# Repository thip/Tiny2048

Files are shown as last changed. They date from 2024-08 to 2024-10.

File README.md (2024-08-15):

# Tiny2048

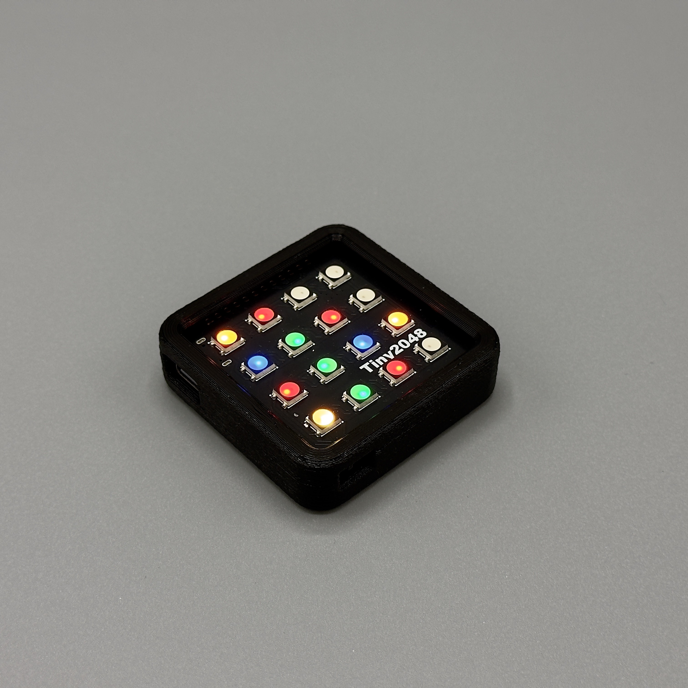
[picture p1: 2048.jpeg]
Photograph of the game running on the assembled hardware


A custom ESP32 dev board with a built in 4x4 RGB LED Matrix and accelerometer.

Built to run an RGB version of 2048 - a simple but addictive game where you try to add up to 2048 by combining matching numbers on sliding tiles. 

Read more about the project at [https://hackaday.io/project/197115-tiny2048](https://hackaday.io/project/197115-tiny2048)

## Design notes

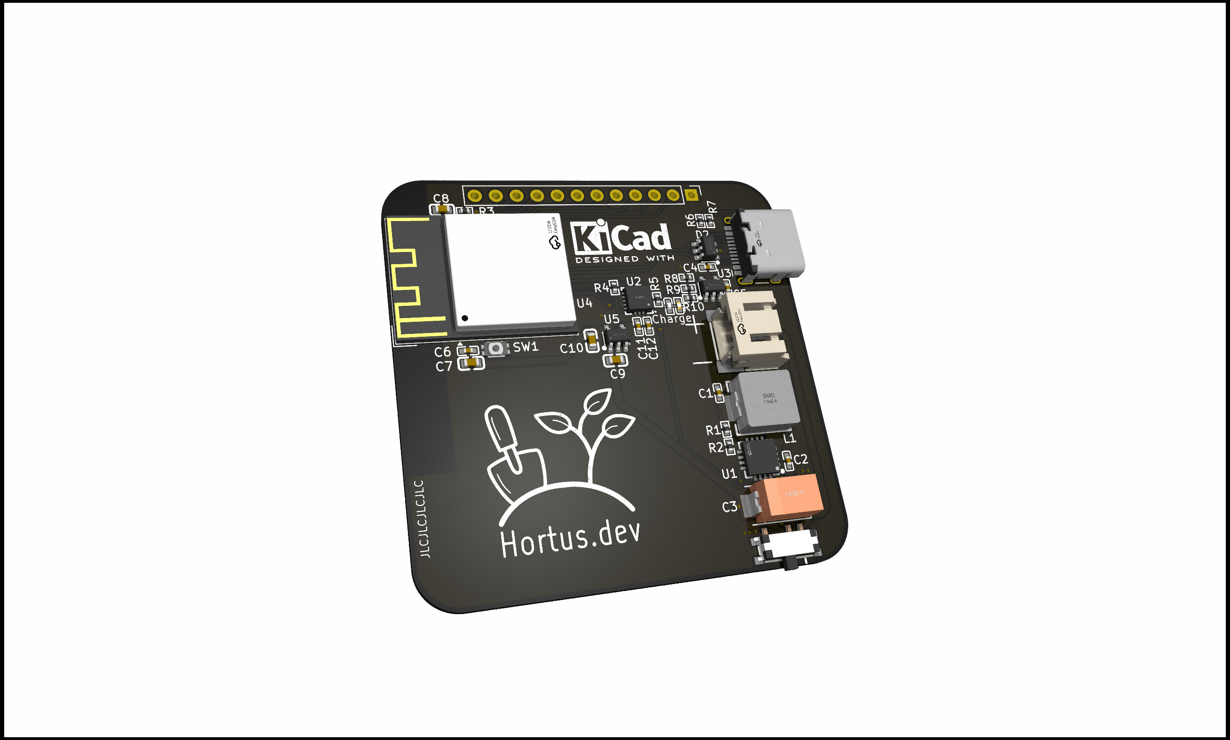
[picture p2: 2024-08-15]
hardware/tiny2048.png

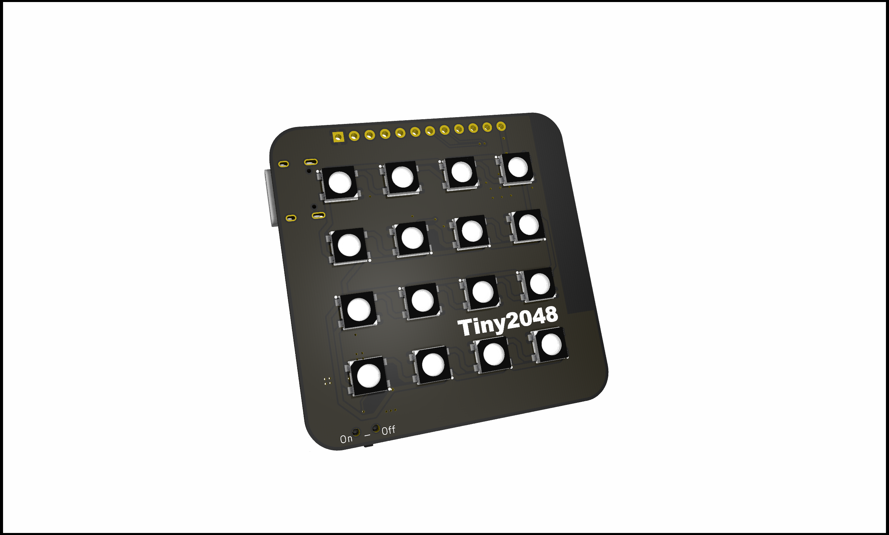
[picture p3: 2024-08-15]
hardware/tiny2048_f.png

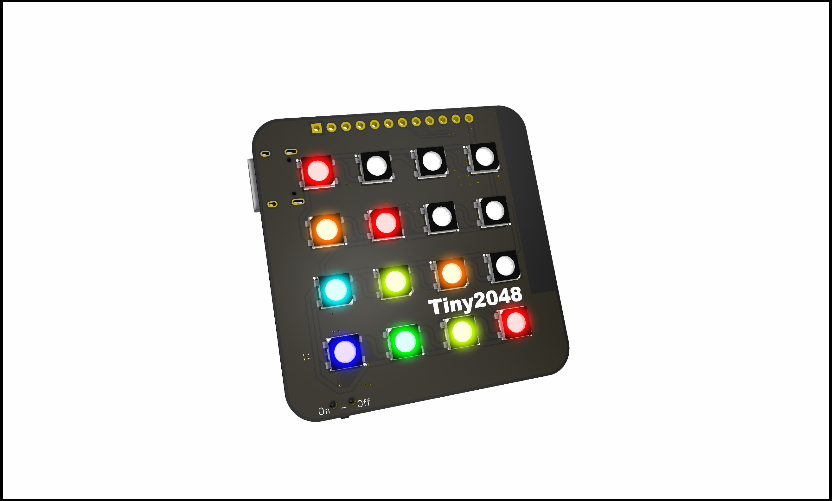
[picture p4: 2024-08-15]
hardware/tiny2048_f_lit.png

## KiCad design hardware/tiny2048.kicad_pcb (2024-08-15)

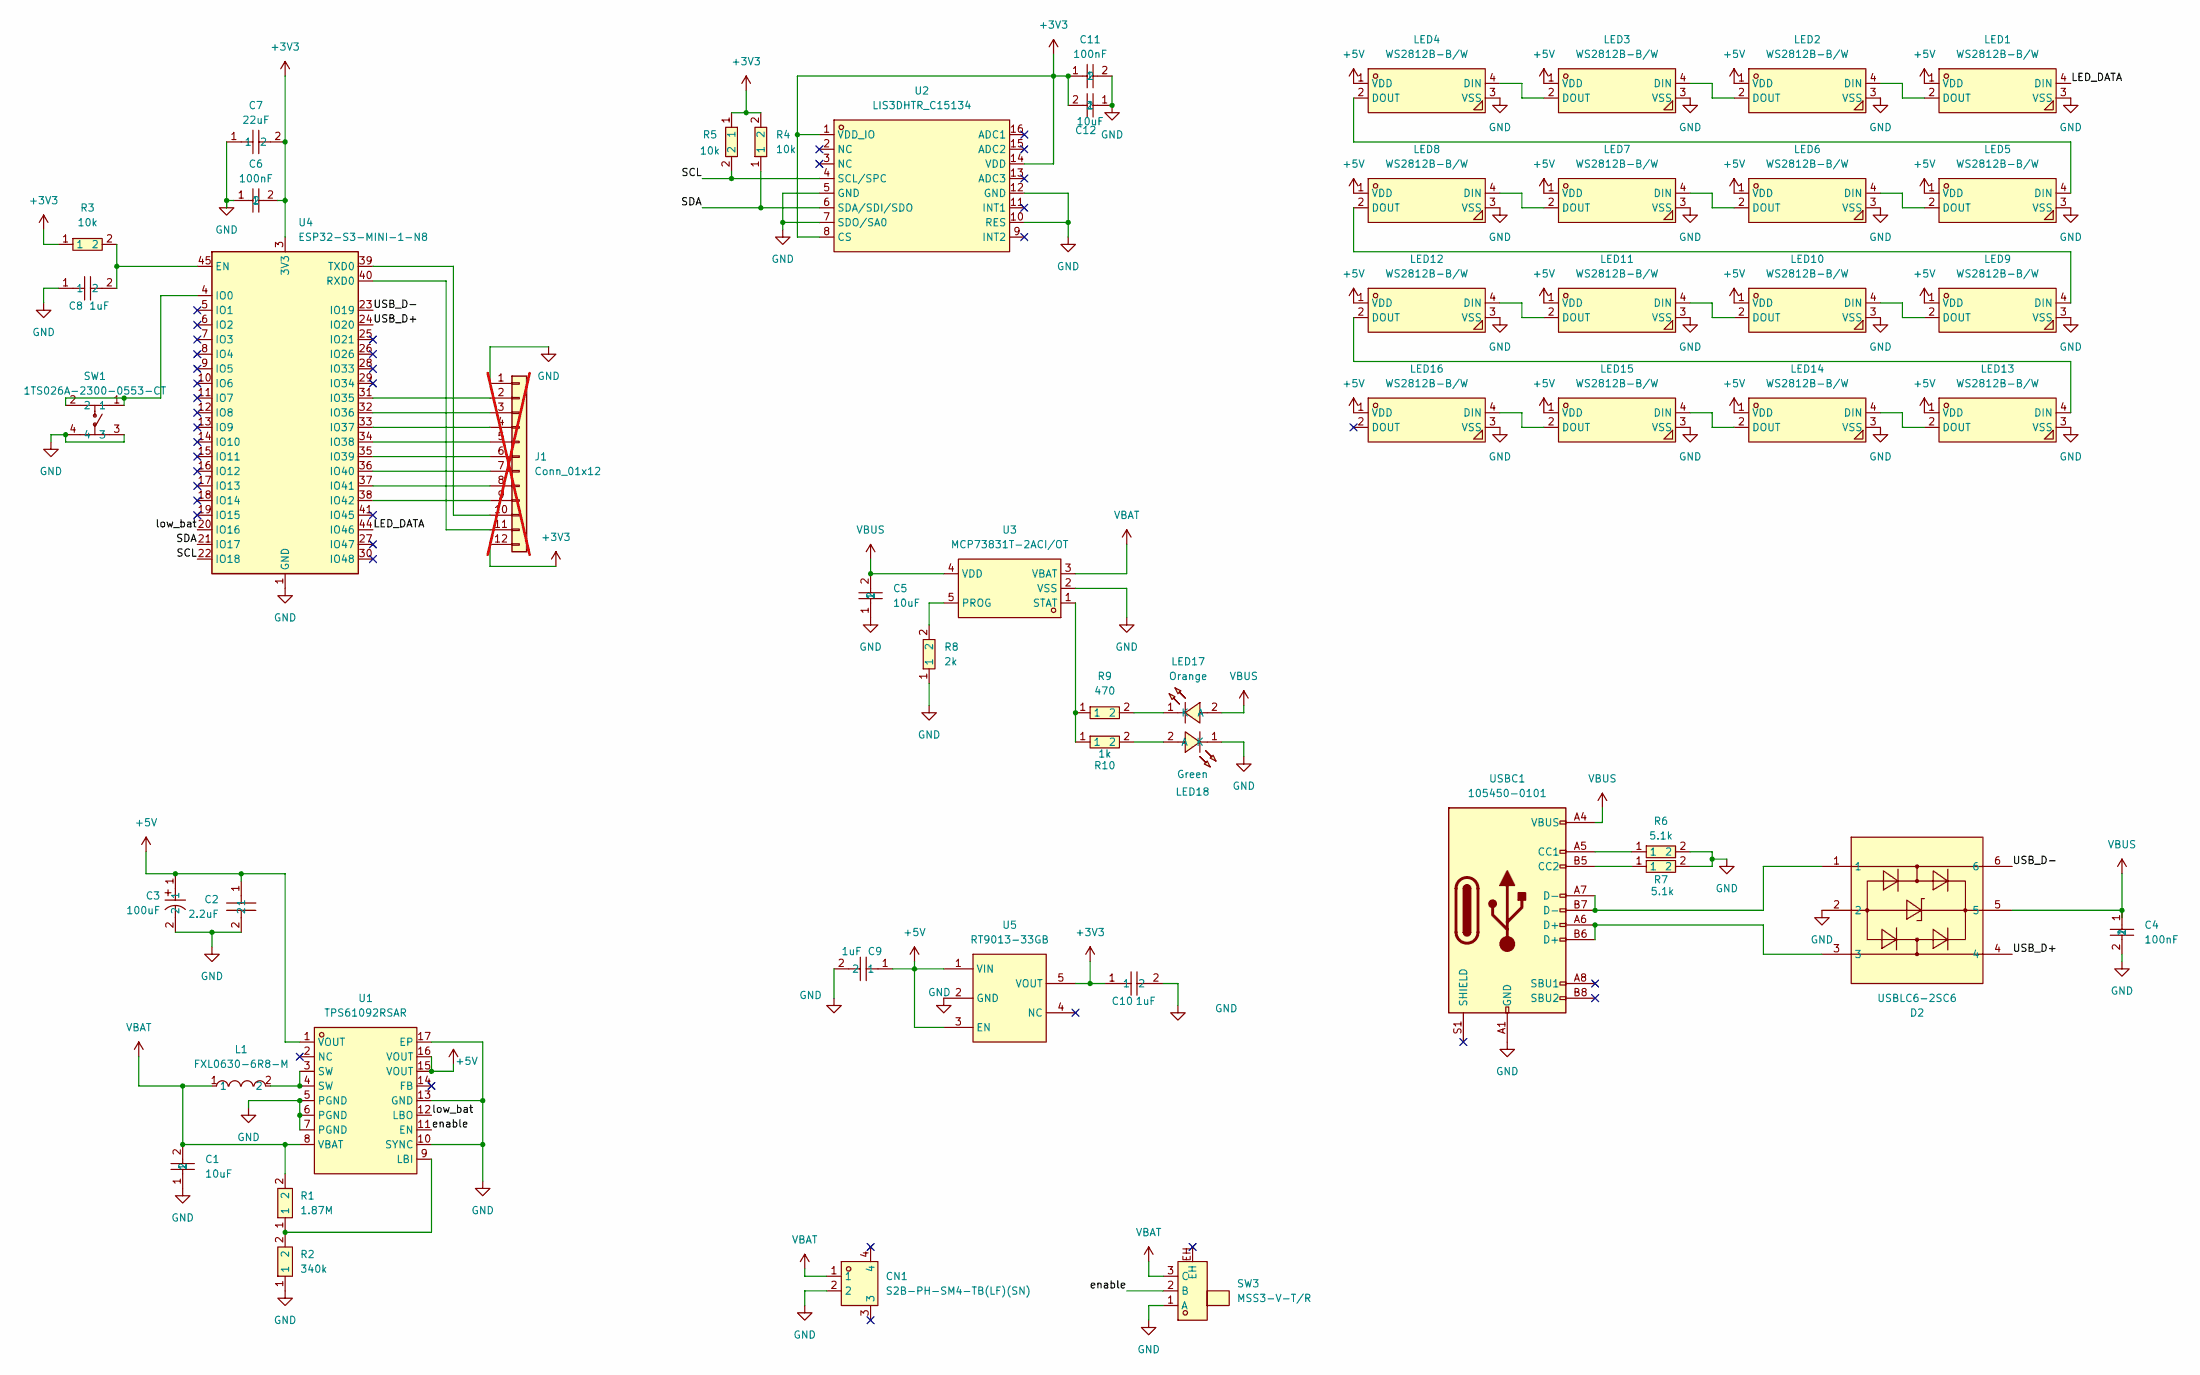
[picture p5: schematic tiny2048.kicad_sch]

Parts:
C1, C5, C12: 10uF; C0402; LCSC Part C15525
C2: 2.2uF; C0402; LCSC Part C12530
C3: 100uF; CAP-SMD_L7.3-W4.3-FD; LCSC Part C215892
C4, C6, C11: 100nF; C0402; LCSC Part C1525
C7: 22uF; C0603; LCSC Part C59461
C8, C9, C10: 1uF; C0603; LCSC Part C15849
CN1: S2B-PH-SM4-TB(LF)(SN); CONN-SMD_P2.00_S2B-PH-SM4-TB-LF-SN; LCSC Part C295747
D2: USBLC6-2SC6; SOT-23-6_L2.9-W1.6-P0.95-LS2.8-BL; LCSC Part C7519
J1: Conn_01x12; PinHeader_1x12_P2.54mm_Vertical; not fitted
L1: FXL0630-6R8-M; IND-SMD_L7.0-W6.6; LCSC Part C167221
LED1, LED2, LED3, LED4, LED5, LED6, LED7, LED8, LED9, LED10, LED11, LED12, LED13, LED14, LED15, LED16: WS2812B-B/W; LED-SMD_4P-L5.0-W5.0-TL_WS2812B-B; LCSC Part C2761795
LED17: Orange; LED0402-RD_ORANGE; LCSC Part C965791
LED18: Green; LED0402-RD_BLUE; LCSC Part C965797
R1: 1.87M; R0402; LCSC Part C368349
R2: 340k; R0402; LCSC Part C409910
R3, R4, R5: 10k; R0402; LCSC Part C25744
R6, R7: 5.1k; R0402; LCSC Part C25905
R8: 2k; R0402; LCSC Part C4109
R9: 470; R0402; LCSC Part C25117
R10: 1k; R0402; LCSC Part C11702
SW1: 1TS026A-2300-0553-CT; SW-SMD_4P-L2.6-W1.6-P0.75-LS3.0; LCSC Part C913791
SW3: MSS3-V-T/R; SW-SMD_MSS3-V-T-R; LCSC Part C495932
U1: TPS61092RSAR; QFN-16_L4.0-W4.0-P0.65-BL-EP2.7-1; LCSC Part C2878944
U2: LIS3DHTR_C15134; LGA-16_L3.0-W3.0-P0.50-TL; LCSC Part C15134
U3: MCP73831T-2ACI/OT; SOT-23-5_L3.0-W1.7-P0.95-LS2.8-BL; LCSC Part C424093
U4: ESP32-S3-MINI-1-N8; ESP32-S2-MINI-1; LCSC Part C2913206
U5: RT9013-33GB; SOT-23-5_L3.0-W1.7-P0.95-LS2.8-BL; LCSC Part C47773
USBC1: 105450-0101; USB_C_Receptacle_HCTL_HC-TYPE-C-16P-01A; LCSC Part C2894897

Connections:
+3V3: C6.2, C7.2, C10.1, C11.1, C12.2, J1.12, R3.1, R4.2, R5.1, U2.1 (VDD_IO), U2.8 (CS), U2.14 (VDD), U4.3 (3V3), U5.5 (VOUT)
+5V: C2.1, C3.1, C9.1, LED1.1 (VDD), LED2.1 (VDD), LED3.1 (VDD), LED4.1 (VDD), LED5.1 (VDD), LED6.1 (VDD), LED7.1 (VDD), LED8.1 (VDD), LED9.1 (VDD), LED10.1 (VDD), LED11.1 (VDD), LED12.1 (VDD), LED13.1 (VDD), LED14.1 (VDD), LED15.1 (VDD), LED16.1 (VDD), U1.1 (VOUT), U1.15 (VOUT), U1.16 (VOUT), U5.1 (VIN), U5.3 (EN)
/LED_DATA: LED1.4 (DIN), U4.44 (IO46)
/SCL: R5.2, U2.4 (SCL/SPC), U4.22 (IO18)
/SDA: R4.1, U2.6 (SDA/SDI/SDO), U4.21 (IO17)
/USB_D+: D2.4, U4.24 (IO20)
/USB_D-: D2.6, U4.23 (IO19)
/enable: SW3.2 (B), U1.11 (EN)
/low_bat: U1.12 (LBO), U4.20 (IO16)
GND: C1.1, C2.2, C3.2, C4.2, C5.1, C6.1, C7.1, C8.1, C9.2, C10.2, C11.2, C12.1, CN1.2, D2.2, J1.1, LED1.3 (VSS), LED2.3 (VSS), LED3.3 (VSS), LED4.3 (VSS), LED5.3 (VSS), LED6.3 (VSS), LED7.3 (VSS), LED8.3 (VSS), LED9.3 (VSS), LED10.3 (VSS), LED11.3 (VSS), LED12.3 (VSS), LED13.3 (VSS), LED14.3 (VSS), LED15.3 (VSS), LED16.3 (VSS), LED18.1 (K), R2.1, R6.2, R7.2, R8.1, SW1.3, SW1.4, SW3.1 (A), U1.5 (PGND), U1.6 (PGND), U1.7 (PGND), U1.10 (SYNC), U1.13 (GND), U1.17 (EP), U2.5 (GND), U2.7 (SDO/SA0), U2.10 (RES), U2.12 (GND), U3.2 (VSS), U4.1 (GND), U4.2 (GND), U4.42 (GND), U4.43 (GND), U4.46 (GND), U4.47 (GND), U4.48 (GND), U4.49 (GND), U4.50 (GND), U4.51 (GND), U4.52 (GND), U4.53 (GND), U4.54 (GND), U4.55 (GND), U4.56 (GND), U4.57 (GND), U4.58 (GND), U4.59 (GND), U4.60 (GND), U4.61 (GND), U4.62 (GND), U4.63 (GND), U4.64 (GND), U4.65 (GND), U5.2 (GND), USBC1.A1 (GND), USBC1.A12 (GND), USBC1.B1 (GND), USBC1.B12 (GND)
unnamed: D2.1, USBC1.A7 (D-), USBC1.B7 (D-)
unnamed: D2.3, USBC1.A6 (D+), USBC1.B6 (D+)
unnamed: J1.2, U4.31 (IO35)
unnamed: J1.3, U4.32 (IO36)
unnamed: J1.4, U4.33 (IO37)
unnamed: J1.5, U4.34 (IO38)
unnamed: J1.6, U4.35 (IO39)
unnamed: J1.7, U4.36 (IO40)
unnamed: J1.8, U4.37 (IO41)
unnamed: J1.9, U4.38 (IO42)
unnamed: J1.10, U4.39 (TXD0)
unnamed: J1.11, U4.40 (RXD0)
unnamed: L1.2, U1.3 (SW), U1.4 (SW)
unnamed: LED1.2 (DOUT), LED2.4 (DIN)
unnamed: LED2.2 (DOUT), LED3.4 (DIN)
unnamed: LED3.2 (DOUT), LED4.4 (DIN)
unnamed: LED4.2 (DOUT), LED5.4 (DIN)
unnamed: LED5.2 (DOUT), LED6.4 (DIN)
unnamed: LED6.2 (DOUT), LED7.4 (DIN)
unnamed: LED7.2 (DOUT), LED8.4 (DIN)
unnamed: LED8.2 (DOUT), LED9.4 (DIN)
unnamed: LED9.2 (DOUT), LED10.4 (DIN)
unnamed: LED10.2 (DOUT), LED11.4 (DIN)
unnamed: LED11.2 (DOUT), LED12.4 (DIN)
unnamed: LED12.2 (DOUT), LED13.4 (DIN)
unnamed: LED13.2 (DOUT), LED14.4 (DIN)
unnamed: LED14.2 (DOUT), LED15.4 (DIN)
unnamed: LED15.2 (DOUT), LED16.4 (DIN)
unnamed: LED17.1 (K), R9.2
unnamed: LED18.2 (A), R10.2
unnamed: R1.1, R2.2, U1.9 (LBI)
unnamed: R8.2, U3.5 (PROG)
unnamed: R9.1, R10.1, U3.1 (STAT)
unnamed: C8.2, R3.2, U4.45 (EN)
unnamed: SW1.1, SW1.2, U4.4 (IO0)
unnamed: R6.1, USBC1.A5 (CC1)
unnamed: R7.1, USBC1.B5 (CC2)
VBAT: C1.2, CN1.1, L1.1, R1.2, SW3.3 (C), U1.8 (VBAT), U3.3 (VBAT)
VBUS: C4.1, C5.2, D2.5, LED17.2 (A), U3.4 (VDD), USBC1.A4 (VBUS), USBC1.A9 (VBUS), USBC1.B4 (VBUS), USBC1.B9 (VBUS)

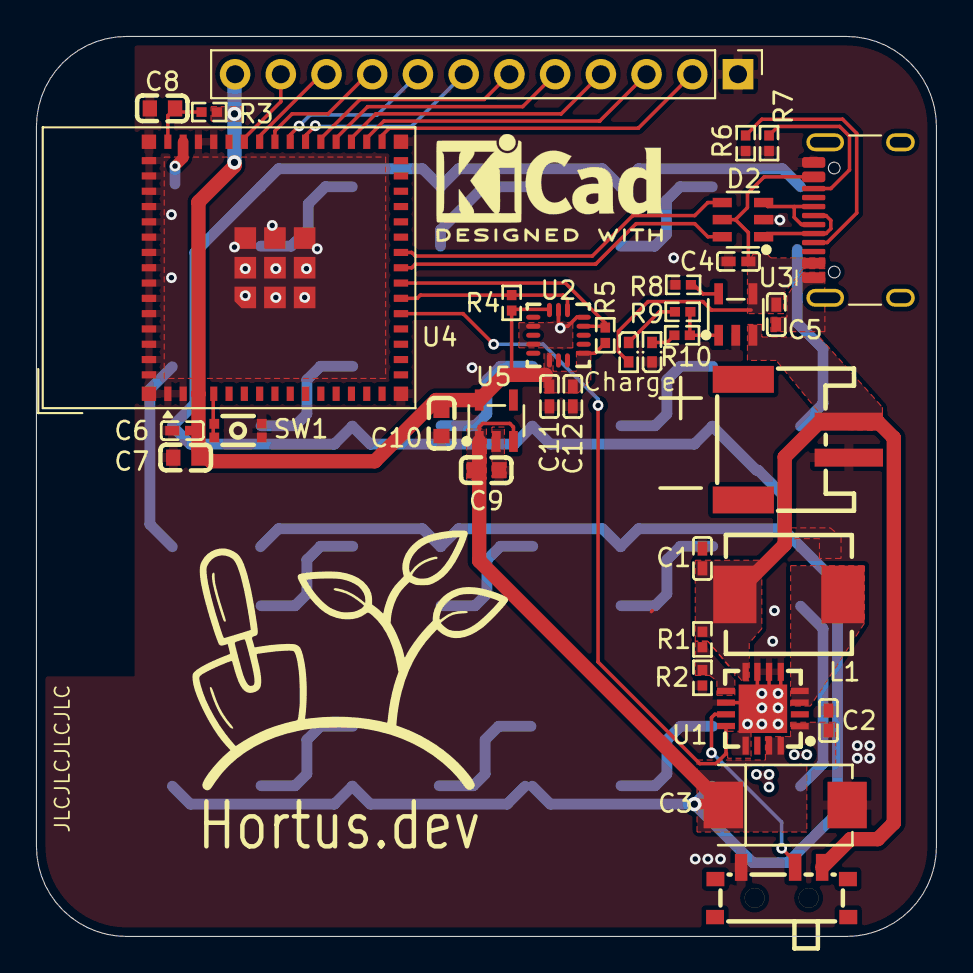
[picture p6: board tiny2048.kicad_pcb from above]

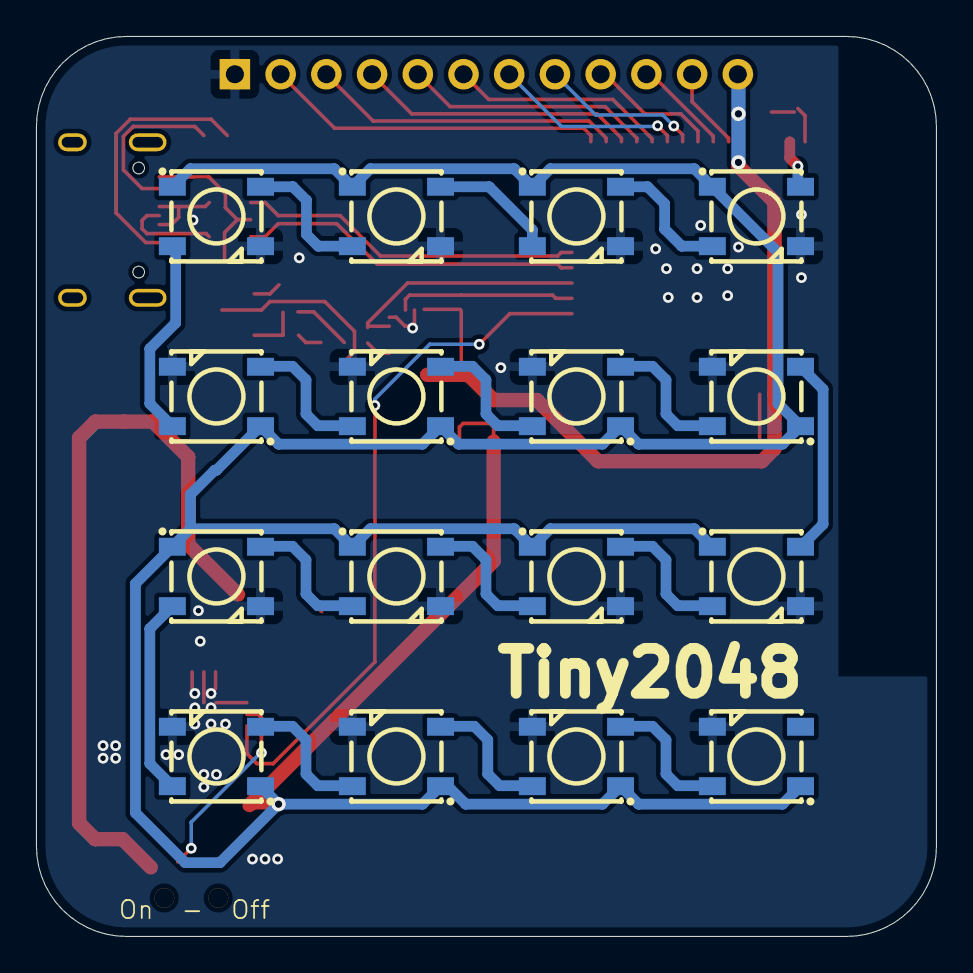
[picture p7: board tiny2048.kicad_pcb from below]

Board: 2 copper layers, 50.0 x 50.0 mm, 52 parts (16 on the bottom side), 49 nets.

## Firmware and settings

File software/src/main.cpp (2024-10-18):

#ifndef   ARDUINO_H
#define   ARDUINO_H

#include <Arduino.h>

#endif

#include <Adafruit_LIS3DH.h>

#include <math.h>
#include <FastLED.h>
#include <Wire.h>
#include <Ticker.h>

#include <Game.hpp>

#define LED_PIN     GPIO_NUM_46
#define COLOR_ORDER GRB
#define BRIGHTNESS  25
#define CHIPSET     WS2812

#define NUM_LEDS    16

Ticker ticker;

Adafruit_LIS3DH lis = Adafruit_LIS3DH();

CRGB leds[NUM_LEDS];

volatile int count = 0;

Game game;

Direction direction = NONE;
bool reset = true;

CRGB value_color(int value){
  switch (value)
  {
  case 2:
    return CHSV( 0, 255, 200);
  
  case 4:
    return CHSV( 50, 255, 200);

  case 8:
    return CHSV( 100, 255, 200);

  case 16:
    return CHSV( 150, 255, 200);

  case 32:
    return CHSV( 200, 255, 200);

  case 64:
    return CHSV( 250, 255, 170+(sin8((count/4)%255)/3));

  case 128:
    return CHSV( 50, 255, 170+(sin8((count/4)%255)/3));

  case 256: 
    return CHSV( 100, 255, 170+(sin8((count/4)%255)/3));

  case 512: 
    return CHSV( 150, 255, 170+(sin8((count/4)%255)/3));

  case 1024:
    return CHSV( 200, 255, 170+(sin8((count/4)%255)/3));

  case 2048:
    return CHSV(sin8(count%255), 255, 255);
  
  default:
    return CRGB::Black;
  }
}

void draw() {
  for (int x = 0; x < 4; x++){
    for (int y = 0; y < 4; y++){
      if (y & 0b01){
        leds[(3-x)+(y*4)] = value_color(game.Tile(x, y));
      } else {
        leds[(x)+(y*4)] = value_color(game.Tile(x, y));
      }
    }
  }
  
  FastLED.show();
}

void showGameWonSequence()
{
  for (int i = 0; i < 3000; i += 50)
  {
    draw();
    delay(50);
  }
  for (int i = 0; i < 5000; i += 50)
  {
    fill_rainbow(leds, 16, (millis() / 10) % 255);
    FastLED.show();
    delay(50);
  }
}

void showGameLostSequence()
{
  delay(2000);

  for (int i = 0; i < 3; i++){
    fill_solid(leds, NUM_LEDS, CRGB::Red);
    FastLED.show();
    delay(500);
    fill_solid(leds, NUM_LEDS, CRGB::Black);
    FastLED.show();
    delay(250);
  }

  delay(1000);
}

void every_milli(){
  count++;
}

void setup() {
  USBSerial.begin(9600);
  USBSerial.setDebugOutput(true);
  USBSerial.write("Starting up\n");
  delay(500);

  FastLED.addLeds<CHIPSET, LED_PIN, COLOR_ORDER>(leds, NUM_LEDS).setCorrection( TypicalLEDStrip );
  FastLED.setBrightness( BRIGHTNESS );
  FastLED.clear(true);
  
  Wire.begin(GPIO_NUM_17, GPIO_NUM_18);
  if (!lis.begin()){
    USBSerial.println("Failed to start accelerometer");
    while(1) yield();
  }

  USBSerial.println("LIS3DH connected");

  lis.read();
  randomSeed(lis.x_g*lis.y_g);

  ticker.attach_ms(1, every_milli);

  game.New();
}

void loop() {  
  lis.read();
  float xAccel = lis.x_g;
  float yAccel = lis.y_g;

  if (reset && !game.Animating()){
    direction = NONE;
    
    if(xAccel > 0.3f){
      direction = RIGHT;
    }

    if(xAccel < -0.3f){
      direction = LEFT;
    }

    if(yAccel > 0.3f){
      direction = UP;
    }

    if(yAccel < -0.3f){
      direction = DOWN;
    }

    if (direction != NONE){
      game.PlayMove(direction);
      reset = false;
    } else if (game.GameWon()){
      showGameWonSequence();
      game.New();
    } else if (!game.MovesAvailable()) {
      showGameLostSequence();
      game.New();
    }
  }

  do {
    game.Step();
    draw();
    delay(50);
    yield();
  } while (game.Animating());


  if (!reset && abs(xAccel) < 0.2f && abs(yAccel) < 0.2f){
    reset = true;
  }

  yield();
}
